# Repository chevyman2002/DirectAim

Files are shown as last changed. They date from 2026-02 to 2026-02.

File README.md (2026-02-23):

# 🎯 DirectAim: The Driverless, Absolute-Positioning Spatial Gun
Created by: Aaron Merritt

Hardware: Teensy 4.0 + BNO086 IMU

## 📖 The Story
DirectAim was born out of a simple desire: to play light gun games with the family without the headache. Standard IR-based light guns (like the Wiimote or AimTrak) require sensor bars, calibration for different screen sizes, and struggle with large projectors or small laptop screens. I wanted a "grab-and-go" solution that worked directly on a laptop, connected a TV in the living room, or a 120-inch projector screen—without custom drivers or expensive proprietary hardware.

DirectAim uses high-fidelity spatial orientation to provide Absolute Mouse Positioning, meaning where you point is where you shoot, regardless of the display technology.

## ❔ Why DirectAim?
Traditional light guns are expensive and finicky. Most DIY solutions use IR LEDs which are a nightmare to set up on different displays. DirectAim is different. It uses inertial measurement to calculate your aim, making it truly display-agnostic.

No IR Bars: Play on a laptop, a TV, or a giant projector screen.

Absolute Accuracy: No "floating" cursor; it maps 1:1 to your screen pixels.

Zero Calibration: Once your DPI and Resolution are set in the firmware, just hit the "Recenter" button and play. If it ever feels "off center", just press the button again and it instantly re-centers.

Tactile Feedback: Designed for a limit-switch trigger for that authentic arcade "click."

## 🧠 How It Works
DirectAim operates differently than a standard mouse or a traditional IR light gun. Here’s the breakdown:

1. Orientation, Not Motion
Most "Air Mice" use relative motion—they tell the computer "move 5 pixels left." This causes "drift," where the gun is pointed at the screen but the cursor is stuck in a corner. DirectAim uses the BNO08x IMU to track Absolute Orientation in 3D space. It calculates the gun's Yaw (left/right) and Pitch (up/down) angles relative to a "Center" point you define.

2. Angular Mapping
Instead of telling Windows to "move," DirectAim tells Windows "I am at these exact coordinates."

The code takes your gun's angle (e.g., 10° Left, 5° Up).

It maps those angles to a Virtual Resolution box that matches your screen's pixel grid.

It then uses the Absolute Mouse HID protocol to "teleport" the cursor to that exact pixel.

3. The "DPI-Aware" Logic
Windows "Scaling" (125%, 150%, etc.) often breaks absolute pointers because it lies to the hardware about how many pixels are actually on the screen. DirectAim includes a Scale Factor in the firmware to math-out this offset, ensuring that your physical point-of-aim and the digital cursor stay perfectly aligned even on high-DPI laptop displays.

4. Hardware Stability
The BNO08x is a powerful sensor, but it is notoriously finicky during startup. This project utilizes a dedicated Hardware Reset (Pin 2). On every power-up, the Teensy pulses the sensor's reset pin to clear the I2C bus. This eliminates the "Initialization Failed" errors common in other DIY builds, making the gun truly plug-and-play.

## 🛠️ The Hardware Build
Brain: Teensy 4.0 (Small, powerful, and native HID support).

Eyes: BNO08x (BNO085/086) 9-axis IMU for drift-free orientation.

Shell: A heavily modified Halo Pistol 3D model, redesigned for secure component mounting.

Trigger: A custom-engineered mechanism that utilizes a limit switch with a lift-arm design for a tactile, "clicky" arcade feel.

### Bill of Materials
|Component|Link|Note|
|---|---|---|
|Teensy 4.0|https://amzn.to/4qgSd0F|High-speed HID-capable brain.|
|SparkFun BNO086 IMU|https://amzn.to/458Fchj|The "eyes" of the gun. 9-axis drift-free tracking.|
|I2C QWIIC Cable Kit|https://amzn.to/45rZCCb|Cut one end off to solder directly to Teensy pins 18, 19, 3.3V, and GND.|
|6pcs Micro Limit Switch|https://amzn.to/4sv4IqV|Use COM and NO blades. Designed for the custom "lift-arm" trigger.|
|6-Color Wire Spools|https://amzn.to/3YzlOX2|You could do with a smaller gauge wire, this is just what I had on hand from a year+ ago.|
|6x6x8mm buttons w/caps|https://amzn.to/4tnO2SN|84Pcs 6×6×8mm Momentary Tactile Tact Push Button Switch with Button Caps of 7 Color,Each Color 12pcs(Black,Red,Blue,Yellow,White, Green,Gray)|
|Soldering Station|https://amzn.to/3NheQDA|I've had this one for over a year and used it quite a bit without any issues so far.|
|3-Pack 10ft USB-Micro Cables|https://amzn.to/4jy5Gi1|I don't have these but may eventually buy them since I'm using a 6ft FireStick cable for now.|
|Machine Screws #6-32x1/2"|https://amzn.to/4a5fOfh|I haven't bought any yet, and may even try 3D printing some, but here's a Lowe's link as well: https://www.lowes.com/pd/Hillman-6-32-x-1-2-in-Slotted-Drive-Machine-Screws-14-Count/3035915|

Trigger Pin - I haven't figured out what I'm going to do for this. I tried 3D printing pins to snugly fit, and even tried printing-in-place the trigger with a solid pin going through holes - but it would snap every time I tried to use it. For now, I have a 1/16" hole going all the way through and I took a cotter pin I had lying around and secured it with that. I'll change this eventually, I think, to avoid getting scratched by it in the future (hasn't happened yet, but it will eventually).

Micro Limit Switch notes (in case the link doesn't work or you want more details on them). These have a roller tip on them as well.
Model: V-156-1C25
Rating: 15A, 1/2Hp, 125/250V AC; 0.6A,125V DC; 0.3A, 250V DC; 0.6A,125V DC; 0.3A, 250V DC
Features: long hinge lever actuator, 1NO+1NC contact configurations, 3 terminals.
Size of Switch: 1.1× 0.63× 0.39in
Diameter of Fixing Hole: 0.13in
Height of Button: 0.12in
Actuator Size: 2.0× 0.16in
Actuator Action: momentary snap action switch

## 🛠️ Troubleshooting
Sensor not found? Ensure the White Wire is connected between Teensy Pin 2 and BNO RST. This pulses the sensor on startup to prevent I2C hang-ups.

Cursor off-center? Ensure the NATIVE_X/Y and SCALE variables in the code match your Windows Display settings exactly.

Axes Inverted? If Left is Right, swap the mapping values in the code: map(..., RES_X, 0) ➔ map(..., 0, RES_X).

## 📜 License & Disclaimer
License: This project is released under the MIT License. You are free to use, modify, and distribute it for personal or commercial use.

Disclaimer of Liability: > This project is provided "as is" without any warranty of any kind. The author is not responsible for any damage to hardware, loss of data, or personal injury resulting from the assembly or use of this device.

Safety Warning: > * This is a DIY electronics project. Always double-check wiring before applying power.

If using a 3D-printed shell shaped like a real firearm, please follow local laws regarding "Orange Tips" and do not use the device in public spaces where it could be mistaken for a real weapon.

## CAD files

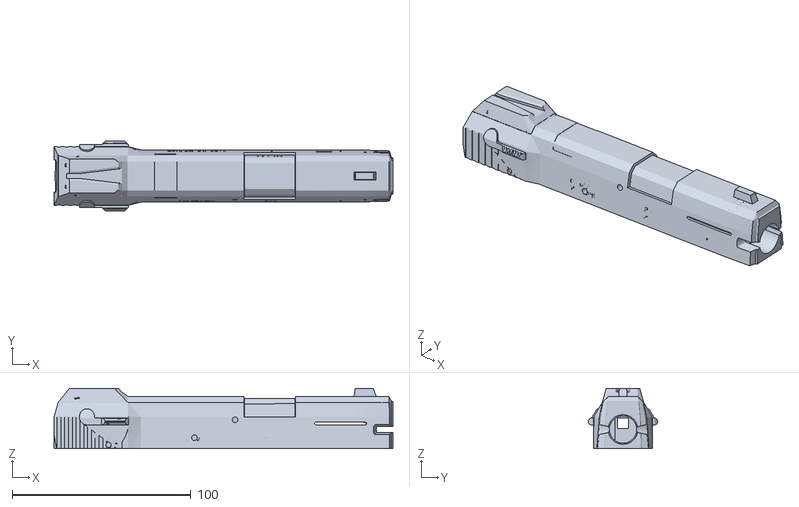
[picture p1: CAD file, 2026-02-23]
STL/Slide.stl
189.5 x 39.0 x 33.6

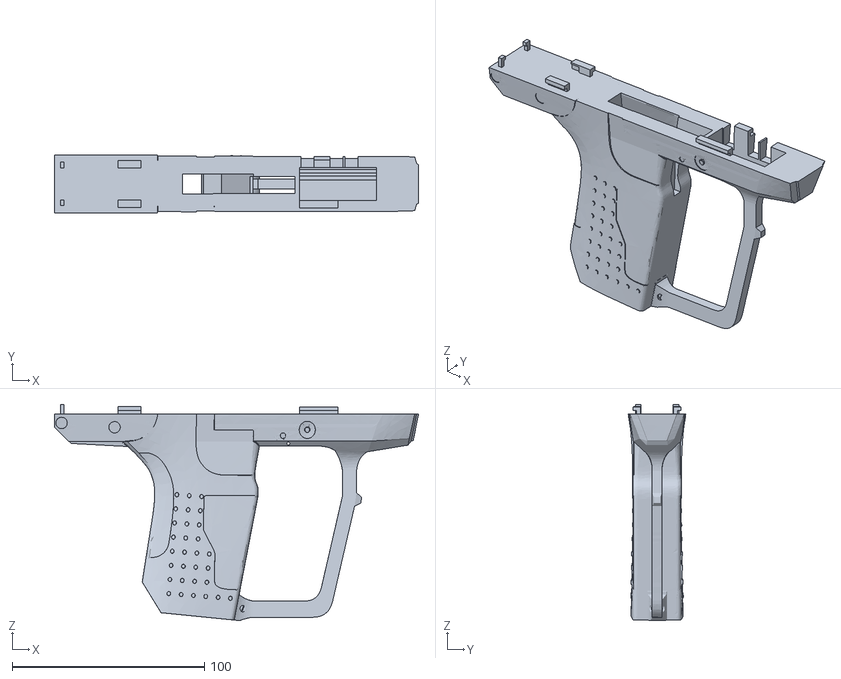
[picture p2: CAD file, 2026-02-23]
STL/Frame.stl
189.4 x 30.0 x 112.6

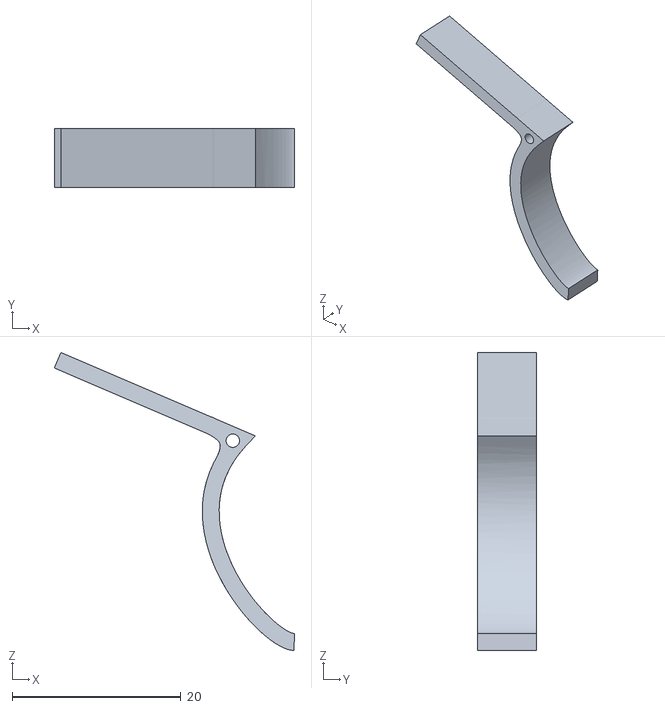
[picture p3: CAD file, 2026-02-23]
STL/Trigger.stl
28.5 x 7.00 x 35.4

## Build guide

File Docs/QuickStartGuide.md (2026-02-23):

# 🚀 DirectAim Quick Start Guide
This guide will get your DirectAim spatial gun flashed and calibrated in minutes.

## 1. Software Setup
Before plugging in your hardware, ensure your environment is ready:

Arduino IDE: Download here (v2.0+ recommended).

Teensy Support: Open the Boards Manager in Arduino IDE, search for Teensy, and install.

BNO08x Library: Open the Library Manager, search for SparkFun BNO08x, and install.

## 2. Prepare the Firmware
Open Firmware/DirectAim/DirectAim.ino in the Arduino IDE.

Configure your Screen: Update the NATIVE_X, NATIVE_Y, and SCALE variables to match your monitor.

Example: If you use a 4K TV at 150% scaling, set NATIVE_X = 3840, NATIVE_Y = 2160, and SCALE = 1.5.

Set USB Type: Go to Tools > USB Type and select "Keyboard + Mouse + Joystick". (This is mandatory for the code to compile).

## 3. Wiring Reference
If you are building your own or troubleshooting, here is the official DirectAim pinout:

|Component|Teensy Pin|HID Output|
|---|---|---|
|Trigger|0|Left Click / Joy 1|
|Recenter (Blue)|1|System Calibration|
|Action 1 (Red)|3|Right Click / Joy 2|
|Action 2 (Green)|4|Keyboard '1' / Joy 3|
|IMU Reset|2|Hardware Pulse (White Wire)|

## 4. Flashing and Calibration
Connect the Teensy to your PC via Micro-USB.

Click Upload in the Arduino IDE.

To Calibrate: Point the gun at the exact center of your screen and tap the Blue Button. Your aim is now locked.

To Reset/Re-flash: No need to open the shell! Hold the Trigger + Blue + Red + Green buttons for 5 seconds. The LED will flash, and the gun will enter programming mode.

## 5. Emulator Setup (Teknoparrot/MAME)
DirectAim is designed to be "plug and play."

Action 2 (Green): This is mapped to the '1' key. In most emulators, this will automatically act as the "Start" or "Coin" button.

Accuracy Tip: If the cursor doesn't reach the corners of your screen, slightly decrease the FOV_X or FOV_Y values in the firmware and re-upload.

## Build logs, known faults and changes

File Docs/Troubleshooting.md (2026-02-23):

# 🛠️ Advanced Troubleshooting & Common Fixes
## 1. The "9-Flash" SOS (IMU Connection Error)
If the Teensy LED flashes 9 times in a row, pauses, and repeats, the code is hanging because it cannot communicate with the BNO08x sensor.

Check Wiring: Ensure the Blue (SDA) and Yellow (SCL) wires are securely connected to Pins 18 and 19.

The White Wire: Ensure the RST pin of the IMU is connected to Teensy Pin 2. The firmware pulses this pin to "wake up" the sensor; without it, the sensor will fail to initialize 90% of the time.

I2C Address: If you are using a non-SparkFun board, the I2C address might be different. The code checks 0x4B and 0x4A by default.

## 2. "Mouse/Joystick Not Declared" Compilation Error
If the Arduino IDE throws errors during compilation stating that Mouse, Keyboard, or Joystick were not declared in this scope:

The Fix: This happens when the IDE defaults to "Serial" mode. Go to Tools > USB Type and select "Keyboard + Mouse + Joystick". This enables the HID libraries required for the gun to function.

## 3. The 15-Second "Nuclear" Reset
If your Teensy becomes completely unresponsive, won't show up as a COM port, or the "Soft Reset" fails:

The Fix:
1. Hold down the physical button on the Teensy board for exactly 15 seconds.
2. The LED will flash briefly. Release the button.
3. The Teensy will spend 30–60 seconds wiping its memory and restoring the factory "Blink" program. You can then re-upload the DirectAim firmware.

## 4. Teknoparrot / Emulator Mapping Issues
If your Action Buttons (Red/Green) aren't registering in certain arcade emulators:

Middle Click Bug: Many emulators do not recognize the Middle Mouse Button (Mouse 3). In v1.2+, the Green Button is mapped to the Keyboard '1' key and Joystick Button 3.

Recommendation: Map "Start" or "Coin" in your emulator to the '1' key or Joy 3.

Input Mode: Ensure your emulator is set to use Raw Input for the best experience with multiple guns.

## 5. Cursor Accuracy & DPI Scaling
If the cursor "teleports" to corners or doesn't reach the edges of the screen:

DPI Check: Right-click your desktop > Display Settings. Check your Scale (e.g., 150%).

Firmware Sync: Ensure the SCALE variable in your code matches this exactly (e.g., 1.5).

FOV Tuning: If the cursor is perfectly centered but stops short of the edges, decrease the FOV_X or FOV_Y values in the code to stretch the movement.

## 6. Axis Inversion
If the gun moves Left when you point Right, or Up when you point Down:

The Fix: You do not need to flip the sensor. In the loop() section of the code, look for the map() functions. Swap the last two numbers.

Example to flip X: Change RES_X, 0 to 0, RES_X.

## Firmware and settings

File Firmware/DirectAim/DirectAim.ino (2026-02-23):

/*
 * ======================================================================================
 * PROJECT: DirectAim IMU Gun
 * VERSION: 1.2.1 (Soft-Reset Update)
 * ======================================================================================
 */

#include <Wire.h>
#include <math.h>
#include <SparkFun_BNO08x_Arduino_Library.h>

#define TRIGGER_PIN 0
#define CENTER_PIN 1
#define BNO08X_RST 2
#define BUTTON_1_PIN 3
#define BUTTON_2_PIN 4
#define LED_PIN 13

float FOV_X = 45.0;
float FOV_Y = 35.0;
float NATIVE_X = 2560;  
float NATIVE_Y = 1600;  
float SCALE = 1.5;      

int RES_X = (int)(NATIVE_X / SCALE); 
int RES_Y = (int)(NATIVE_Y / SCALE);

BNO08x myIMU;
float yawOffset = 0, pitchOffset = 0;
bool triggerHeld = false, b1Held = false, b2Held = false;

// Reset Logic
unsigned long resetTimer = 0;
const unsigned long RESET_THRESHOLD = 5000; 

void setup() {
  Serial.begin(115200);
  pinMode(LED_PIN, OUTPUT);
  pinMode(TRIGGER_PIN, INPUT_PULLUP);
  pinMode(CENTER_PIN, INPUT_PULLUP);
  pinMode(BUTTON_1_PIN, INPUT_PULLUP);
  pinMode(BUTTON_2_PIN, INPUT_PULLUP);
  
  pinMode(BNO08X_RST, OUTPUT);
  digitalWrite(BNO08X_RST, LOW);
  delay(100);
  digitalWrite(BNO08X_RST, HIGH);
  delay(1000); 

  Wire.begin();
  Wire.setClock(100000); 

  if (myIMU.begin(0x4B, Wire) == false) {
    if (myIMU.begin(0x4A, Wire) == false) {
      while (1) { digitalWrite(LED_PIN, HIGH); delay(100); digitalWrite(LED_PIN, LOW); delay(100); }
    }
  }

  myIMU.enableGameRotationVector(10);
  Mouse.screenSize(RES_X, RES_Y);
  Joystick.useManualSend(true);
}

void loop() {
  // --- 1. THE SOFT RESET LOGIC (TOP PRIORITY) ---
  // Check if ALL 4 buttons are physically held LOW
  bool triggerP = (digitalRead(TRIGGER_PIN) == LOW);
  bool centerP  = (digitalRead(CENTER_PIN) == LOW);
  bool redP     = (digitalRead(BUTTON_1_PIN) == LOW);
  bool greenP   = (digitalRead(BUTTON_2_PIN) == LOW);

  if (triggerP && centerP && redP && greenP) {
    if (resetTimer == 0) {
      resetTimer = millis(); 
      Serial.println("Reset Timer Started...");
    } 
    
    // Visual Feedback: Blink the LED faster as we get closer to 5s
    unsigned long elapsed = millis() - resetTimer;
    if (elapsed > 100) digitalWrite(LED_PIN, (millis() / 100) % 2); 

    if (elapsed > RESET_THRESHOLD) {
      Serial.println("Jumping to Bootloader!");
      // Final fast strobe to confirm success
      for(int i=0; i<20; i++) { digitalWrite(LED_PIN, !digitalRead(LED_PIN)); delay(20); }
      _reboot_Teensyduino_(); 
    }
    
    // IMPORTANT: We return here so we don't send mouse/keyboard 
    // movements while trying to reset.
    return; 
  } else {
    resetTimer = 0; 
    // If not resetting, make sure LED is off (or stays on for power indicator)
    digitalWrite(LED_PIN, LOW); 
  }

  // --- 2. IMU / MOUSE MOVEMENT ---
  if (myIMU.wasReset()) { myIMU.enableGameRotationVector(10); }

  if (myIMU.getSensorEvent() == true) {
    if (myIMU.getSensorEventID() == SENSOR_REPORTID_GAME_ROTATION_VECTOR) {
      float qI = myIMU.getQuatI();
      float qJ = myIMU.getQuatJ();
      float qK = myIMU.getQuatK();
      float qR = myIMU.getQuatReal();

      float yaw = atan2(2.0 * (qR * qK + qI * qJ), 1.0 - 2.0 * (qJ * qJ + qK * qK));
      float pitch = asin(2.0 * (qR * qJ - qK * qI));
      yaw *= (180.0 / M_PI);
      pitch *= (180.0 / M_PI);

      // Normal Recenter (Only if not holding all buttons)
      if (centerP) {
        yawOffset = yaw;
        pitchOffset = pitch;
      }

      float dX = yaw - yawOffset;
      float dY = pitch - pitchOffset;
      if (dX > 180) dX -= 360; if (dX < -180) dX += 360;

      long mX = map(dX * 100, -FOV_X * 50, FOV_X * 50, RES_X, 0);
      long mY = map(dY * 100, -FOV_Y * 50, FOV_Y * 50, RES_Y, 0);
      Mouse.moveTo(constrain(mX, 0, RES_X), constrain(mY, 0, RES_Y));

      Joystick.X(map(dX * 100, -FOV_X * 50, FOV_X * 50, 1023, 0));
      Joystick.Y(map(dY * 100, -FOV_Y * 50, FOV_Y * 50, 1023, 0));
    }
  }

  // --- 3. STANDARD BUTTON OUTPUTS ---
  handleButton(TRIGGER_PIN, triggerHeld, MOUSE_LEFT, 0, 1);
  handleButton(BUTTON_1_PIN, b1Held, MOUSE_RIGHT, 0, 2);
  handleButton(BUTTON_2_PIN, b2Held, 0, '1', 3);

  Joystick.send_now();
}

void handleButton(int pin, bool &state, int mouseBtn, char keyChar, int joyBtn) {
  if (digitalRead(pin) == LOW) {
    if (!state) {
      if (mouseBtn != 0) Mouse.press(mouseBtn);
      if (keyChar != 0) Keyboard.press(keyChar);
      Joystick.button(joyBtn, 1);
      state = true;
    }
  } else {
    if (state) {
      if (mouseBtn != 0) Mouse.release(mouseBtn);
      if (keyChar != 0) Keyboard.release(keyChar);
      Joystick.button(joyBtn, 0);
      state = false;
    }
  }
}

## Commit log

2026-01-12 Revise README with project details and hardware info
    Expanded the README to include detailed project description, functionality, hardware build, and bill of materials.
2026-01-12 Initial upload of code and STL files as-is.
    There are many more changes expected to come, but this is where I'm at with a PoC, more or less.
    [Frame.stl, Slide.stl, Trigger.stl]
2026-01-12 Revise Quick Start Guide for DirectAim project
    Updated the Quick Start Guide to reflect the project name and improved formatting for the wiring diagram and sections.
2026-02-23 v1.2.1: Finalized "Sealed-Shell" Hardware and Production Logic
    Firmware: Introduced Soft-Reset logic with a prioritized 5s hold timer and LED visual feedback. Press and hold all buttons for 5 seconds to enter programming mode (Teensy4).
    Input Fix: Remapped Green button to Keyboard '1' + Joy 3 for seamless Teknoparrot/MAME integration.
    Stability: Added logic-lockout during reset sequence to prevent ghost inputs.
    Hardware: Updated STL files with final ergonomics and internal component mounting improvements.
    UX: Verified 1:1 absolute tracking on 150% DPI displays with zero drift.
    [Frame.stl, Slide.stl, Trigger.stl]
2026-02-23 Convert Bill of Materials to Markdown table format
    Formatted the Bill of Materials section into a table for better readability. Nothing I did would fix it so I manually edited it in the GUI.
2026-02-23 Revise Quick Start Guide for DirectAim setup
    Updated details for the new buttons and other changes.
2026-02-23 Update troubleshooting guide with advanced fixes
    Updated troubleshooting and included a couple of common issues.
